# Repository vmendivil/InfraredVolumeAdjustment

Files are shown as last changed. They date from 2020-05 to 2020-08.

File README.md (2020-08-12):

### What this project does?

This project is inteded to record IR signals from a remote controler, specially volume up and volume down signals, then read the volume level from a device and based on preconfigured parameters decide if the volume is above or below of what is an ideal level of sound and based on that send IR signals to the device to increase or decrease the volume in order to try to keep a constant level of sound.

The project can receive a parameter to decide what piece of code to execute which include just reading audio levels, or independantly sending IR volume up/down signals as well as running the application that will merge all the functionality to effectively read sound levels and send IR signals as needed.

### BOM

* (1) Raspberry PI 4
* (1) [IT Transmitter](https://www.digikey.com/product-detail/en/everlight-electronics-co-ltd/IR333C-H0-L10/1080-1082-ND/2675573)
* (1) [IR Receiver](https://www.digikey.com/product-detail/en/vishay-semiconductor-opto-division/TSOP38238/751-1227-ND/1681362)
* (1) [Analog-Digital Converter PCF8591](https://www.nxp.com/docs/en/data-sheet/PCF8591.pdf)
* (1) Led
* (3) Resistance 10k
* (2) Resistance 220k
* (1) [Transistory NPN](https://www.digikey.com/product-detail/en/on-semiconductor/PN2222ATF/PN2222ATFCT-ND/3504402)
* (1) [Audio Detector](https://www.digikey.com/product-detail/en/sparkfun-electronics/SEN-14262/1568-1721-ND/7725299)

### Circuit Diagram

Circuit diagram source file is part of this repository. Frizting is the software tool used for its design.

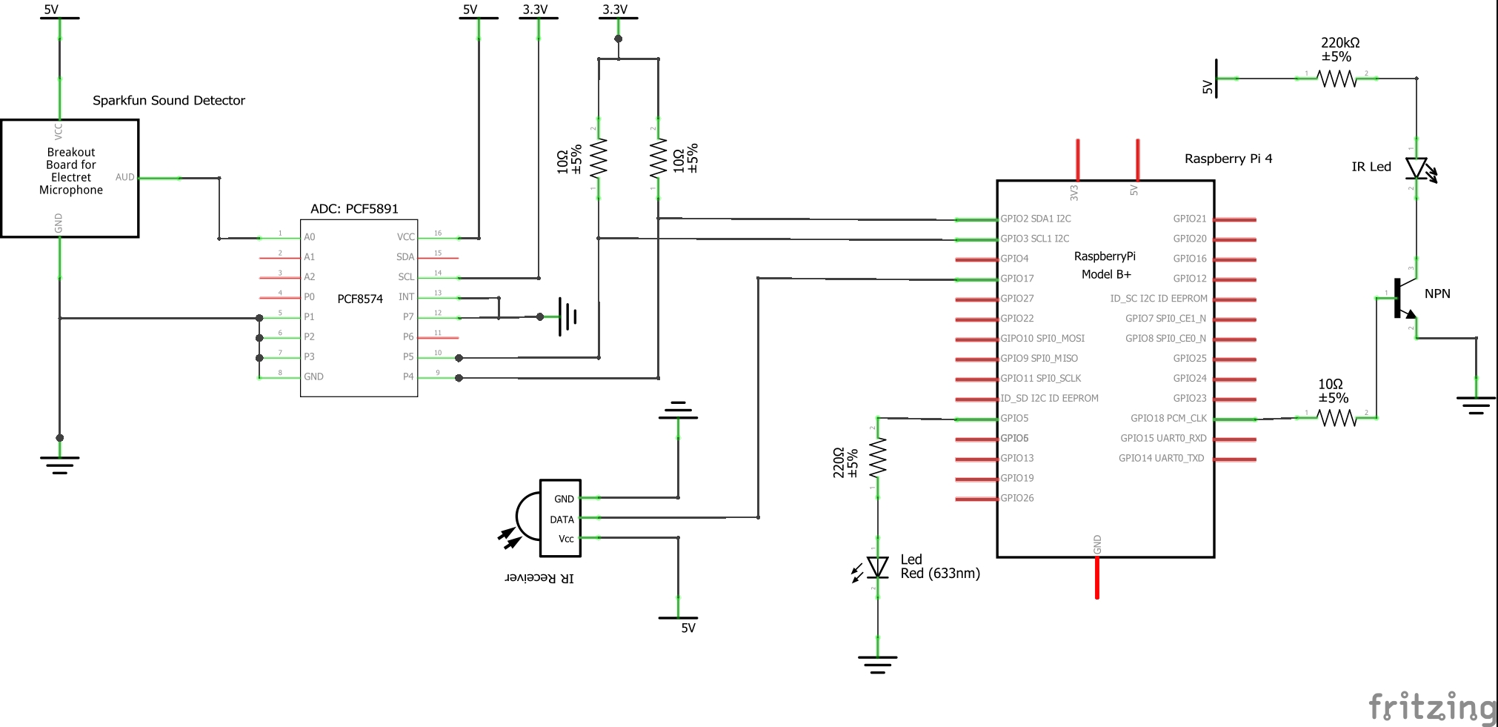
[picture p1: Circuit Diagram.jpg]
Circuit Diagram


#### Analog-Digital Converter

Diagram is using a different chip because the drawing software didn't have the chip that was effectively used. 

Correct chip is ADC PCF8591. Correct port mapping for the chip is displayed below. Physical connections in the diagram are correct and match PCF8591 pins.

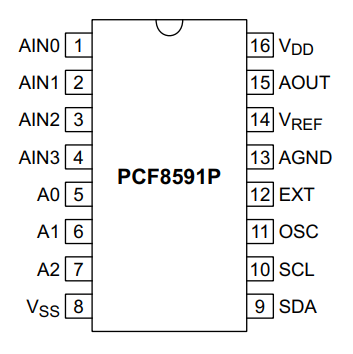
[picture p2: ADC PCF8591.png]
PCF8591


#### Sound Detector

The diagram represents an audio input. Current implementation uses Sparkfun Sound Detector and uses Envelope pin output to determine the sound level.

### Configure I2C

The i2c interface in raspberry is closed by default, it has to be open manually.

Steps:

	1) Run command: sudo raspi-config
	2) Follow path:
		a. 5 Interfacing Options
		b. P5 I2C
		c. Yes
		d. Finish
	3) Restart Raspberry

To validate i2c module is started:

	• Command: lsmod | grep i2c

Install i2c-Tools

	• Command: sudo apt-get install i2c-tools

Detect device addresses (which will be used in the program):

	• Command: i2cdetect -y 1

Restart Raspberry.

### Functions

	1) Record IR signals from remote controller.
	2) Send IR signals from raspberry and IR transmitter to device.
	3) Read and process data from sound detector
	4) Define rules about how program will work to process sound levels from device and send IR signals to device.
	5) Configuration of profiles and audio levels.
	6) Manual adjustments of level on the fly.

### Code and Libraries

This program uses F# and Python for different purposes.

F# is used as the main programing language to drive the logic that will read the sound level and will trigger the instructions to increase/decrease the volume level.

Python is used to have quick and easy access to pigpio library. This library provides an example on how to record and reproduce IR signals.

F# uses Unosquare.RaspberryIO NuGet package. Python uses pigpio library.

### Install pigpio in Raspberry

Follow instructions: http://abyz.me.uk/rpi/pigpio/download.html

### How to record IR signals from console

	1) Connect IR receiver to Raspberry.
	2) Download python pigpio script to record and reproduce IR signals.
		a. Link: http://abyz.me.uk/rpi/pigpio/examples.html#Python%20code
			i. IR Record and Playback: http://abyz.me.uk/rpi/pigpio/code/irrp_py.zip
	3) Start pigpio daemon: sudo pigpiod
	4) To record the GPIO connected to the IR receiver, a file for the recorded codes, and the codes to be recorded are given.
		a. Command: sudo python irrp.py -r -g4 -fir-codes vol+ vol- 1 2 3 4 5 6 7 8 9 0
	5) Recorded signals get saved in a json file format
	6) Stop pigpio daemon: sudo killall pigpiod

To get help on available commands and options, run command: sudo python irrp.py -h

### How to playback IR signals from console

	1) Connect the IR transmitter to Raspberry
	2) Download python pigpio script to record and reproduce IR signals.
		a. Link: http://abyz.me.uk/rpi/pigpio/examples.html#Python%20code
			i. IR Record and Playback: http://abyz.me.uk/rpi/pigpio/code/irrp_py.zip
	3) Start pigpio daemon: sudo pigpiod
	4) To playback IR signals through the IR transmitter, we need to provide the file generated while recording IR signals and the commands that we want to reproduce.
		a. Command: sudo python irrp.py -p -g18 -fir-codes 2 3 4
	5) Stop pigpio daemon: sudo killall pigpiod

### Read data from Sound Detector

Sound detector functionality is explanied in the below link. We are using the Envelope output.

https://learn.sparkfun.com/tutorials/sound-detector-hookup-guide

### Rules on how the program Volume Leveler program works

	1) Program will be written in F#, why? Just for fun.
	2) Program will call functions inside python script to record/send IR signals.
	3) A range should be configured to determine acceptable audio levels.
		a. If above that range, reduce the volume.
		b. If below that range, increase the volume.
	4) A maximum/minimum threshold of allowed IR signals must be configured to prevent indefinitely increase/decrease of volume.
	5) Should provide the ability to select what profile/configuration will be used by the IR transmitter.
	6) A rate per second read frequency should be configured for audio lectures.

### How to run the program

The program follows some assumptions:

	a) You have python installed
	b) You have pigpio python package installed
	c) You have dotNet installed
	d) You can properly ssh into your Raspberry

API functionality will be added in the future.

#### Deploy app from outside the Raspberry

	1) Clone repo
	2) Open PowerShell and modify/run Deploy.ps1 script
		a. Script assumes you can ssh to your Raspberry.
		b. $SshPrivateKey must be the path to your private key
		c. Update the IP and path where you will be deploying your code

#### Run console app

	1) Ssh to your raspberry and navigate to the folder where the code was deployed
	2) Run program: dotnet AutomaticInfraredAudioLeveler.dll

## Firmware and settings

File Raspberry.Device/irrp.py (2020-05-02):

#!/usr/bin/env python

# irrp.py
# 2015-12-21
# Public Domain

"""
A utility to record and then playback IR remote control codes.

To record use

./irrp.py -r -g4 -fcodes 1 2 3 4 5 6

where

-r record
-g the GPIO connected to the IR receiver
-f the file to store the codes

and 1 2 3 4 5 6 is a list of codes to record.

To playback usedir

./irrp.py -p -g17 -fcodes 2 3 4

where

-p playback
-g the GPIO connected to the IR transmitter
-f the file storing the codes to transmit

and 2 3 4 is a list of codes to transmit.

OPTIONS

-r record
-p playback
-g GPIO (receiver for record, transmitter for playback)
-f file

id1 id2 id3 list of ids to record or transmit

RECORD

--glitch     ignore edges shorter than glitch microseconds, default 100 us
--post       expect post milliseconds of silence after code, default 15 ms
--pre        expect pre milliseconds of silence before code, default 200 ms
--short      reject codes with less than short pulses, default 10
--tolerance  consider pulses the same if within tolerance percent, default 15
--no-confirm don't require a code to be repeated during record

TRANSMIT

--freq       IR carrier frequency, default 38 kHz
--gap        gap in milliseconds between transmitted codes, default 100 ms
"""

import time
import json
import os
import argparse

import pigpio # http://abyz.co.uk/rpi/pigpio/python.html

p = argparse.ArgumentParser()

g = p.add_mutually_exclusive_group(required=True)
g.add_argument("-p", "--play",   help="play keys",   action="store_true")
g.add_argument("-r", "--record", help="record keys", action="store_true")

p.add_argument("-g", "--gpio", help="GPIO for RX/TX", required=True, type=int)
p.add_argument("-f", "--file", help="Filename",       required=True)

p.add_argument('id', nargs='+', type=str, help='IR codes')

p.add_argument("--freq",      help="frequency kHz",   type=float, default=38.0)

p.add_argument("--gap",       help="key gap ms",        type=int, default=100)
p.add_argument("--glitch",    help="glitch us",         type=int, default=100)
p.add_argument("--post",      help="postamble ms",      type=int, default=15)
p.add_argument("--pre",       help="preamble ms",       type=int, default=200)
p.add_argument("--short",     help="short code length", type=int, default=10)
p.add_argument("--tolerance", help="tolerance percent", type=int, default=15)

p.add_argument("-v", "--verbose", help="Be verbose",     action="store_true")
p.add_argument("--no-confirm", help="No confirm needed", action="store_true")

args = p.parse_args()

GPIO       = args.gpio
FILE       = args.file
GLITCH     = args.glitch
PRE_MS     = args.pre
POST_MS    = args.post
FREQ       = args.freq
VERBOSE    = args.verbose
SHORT      = args.short
GAP_MS     = args.gap
NO_CONFIRM = args.no_confirm
TOLERANCE  = args.tolerance

POST_US    = POST_MS * 1000
PRE_US     = PRE_MS  * 1000
GAP_S      = GAP_MS  / 1000.0
CONFIRM    = not NO_CONFIRM
TOLER_MIN =  (100 - TOLERANCE) / 100.0
TOLER_MAX =  (100 + TOLERANCE) / 100.0

last_tick = 0
in_code = False
code = []
fetching_code = False

def backup(f):
   """
   f -> f.bak -> f.bak1 -> f.bak2
   """
   try:
      os.rename(os.path.realpath(f)+".bak1", os.path.realpath(f)+".bak2")
   except:
      pass

   try:
      os.rename(os.path.realpath(f)+".bak", os.path.realpath(f)+".bak1")
   except:
      pass

   try:
      os.rename(os.path.realpath(f), os.path.realpath(f)+".bak")
   except:
      pass

def carrier(gpio, frequency, micros):
   """
   Generate carrier square wave.
   """
   wf = []
   cycle = 1000.0 / frequency
   cycles = int(round(micros/cycle))
   on = int(round(cycle / 2.0))
   sofar = 0
   for c in range(cycles):
      target = int(round((c+1)*cycle))
      sofar += on
      off = target - sofar
      sofar += off
      wf.append(pigpio.pulse(1<<gpio, 0, on))
      wf.append(pigpio.pulse(0, 1<<gpio, off))
   return wf

def normalise(c):
   """
   Typically a code will be made up of two or three distinct
   marks (carrier) and spaces (no carrier) of different lengths.

   Because of transmission and reception errors those pulses
   which should all be x micros long will have a variance around x.

   This function identifies the distinct pulses and takes the
   average of the lengths making up each distinct pulse.  Marks
   and spaces are processed separately.

   This makes the eventual generation of waves much more efficient.

   Input

     M    S   M   S   M   S   M    S   M    S   M
   9000 4500 600 540 620 560 590 1660 620 1690 615

   Distinct marks

   9000                average 9000
   600 620 590 620 615 average  609

   Distinct spaces

   4500                average 4500
   540 560             average  550
   1660 1690           average 1675

   Output

     M    S   M   S   M   S   M    S   M    S   M
   9000 4500 609 550 609 550 609 1675 609 1675 609
   """
   if VERBOSE:
      print("before normalise", c)
   entries = len(c)
   p = [0]*entries # Set all entries not processed.
   for i in range(entries):
      if not p[i]: # Not processed?
         v = c[i]
         tot = v
         similar = 1.0

         # Find all pulses with similar lengths to the start pulse.
         for j in range(i+2, entries, 2):
            if not p[j]: # Unprocessed.
               if (c[j]*TOLER_MIN) < v < (c[j]*TOLER_MAX): # Similar.
                  tot = tot + c[j]
                  similar += 1.0

         # Calculate the average pulse length.
         newv = round(tot / similar, 2)
         c[i] = newv

         # Set all similar pulses to the average value.
         for j in range(i+2, entries, 2):
            if not p[j]: # Unprocessed.
               if (c[j]*TOLER_MIN) < v < (c[j]*TOLER_MAX): # Similar.
                  c[j] = newv
                  p[j] = 1

   if VERBOSE:
      print("after normalise", c)

def compare(p1, p2):
   """
   Check that both recodings correspond in pulse length to within
   TOLERANCE%.  If they do average the two recordings pulse lengths.

   Input

        M    S   M   S   M   S   M    S   M    S   M
   1: 9000 4500 600 560 600 560 600 1700 600 1700 600
   2: 9020 4570 590 550 590 550 590 1640 590 1640 590

   Output

   A: 9010 4535 595 555 595 555 595 1670 595 1670 595
   """
   if len(p1) != len(p2):
      return False

   for i in range(len(p1)):
      v = p1[i] / p2[i]
      if (v < TOLER_MIN) or (v > TOLER_MAX):
         return False

   for i in range(len(p1)):
       p1[i] = int(round((p1[i]+p2[i])/2.0))

   if VERBOSE:
      print("after compare", p1)

   return True
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

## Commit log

2020-05-01 Delete lirc control config file
    I was able to record a file with lirc but when sending signals, it was flashing, but device wasn't doing anything at all, so I assume the recording of the file didn't work.
2020-05-02 Adding gigpio config file
    This new file is generated using gigpio. All buttons added in the json file are currently working.
2020-05-02 Creating script for just Audio Sensor.
2020-05-06 Schematic circuit diagram.
    [Circuit Diagram.fzz]
2020-05-06 Diagram before routing voltages to raspberry.
    [Circuit Diagram.fzz]
2020-05-06 Audio diagram and updated sound levels.
    [Circuit Diagram.fzz]
2020-05-06 Adding i2c configuration.
2020-05-06 Updated BOM
2020-05-06 Drawing of ADC chip.
    [Circuit Diagram.fzz]
2020-05-06 Updating ADC comment.
2020-05-27 Convert audio sensor recursive operations Async.
2020-05-27 Fixing variable names on printValues member.
2020-06-03 Added Singleton Global type to additional function control
    Adding a singleton Global type in order to manipualte accorss the application some functionalities that can be propagated to execution threads. One sample is added in the Test.fs file on how this might be implemented.
    Another addition in here is a test for the output led.
    At this point I did some changes in the physical circuit since I clean up a bit the wiring and I had some issues because of bad connections or a pending reboot on the PI, but it got resolved and is working up to this point.
2020-06-04 Enhance menu when IR Audio Leveler running.
    Moved to top level pigpiod daemon to start and stop once during the application life cycle.
    Added functionality to increase audio sensor levels and IR max and min increases on the fly (I haven't tested with a device but at least from the console looks ok).
